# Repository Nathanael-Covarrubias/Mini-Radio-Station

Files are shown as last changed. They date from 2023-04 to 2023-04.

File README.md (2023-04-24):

# Mini-Radio-Station
FM Transmitter-NS73M

This project is a simple FM Transmitter that is deisgned to be a module for the M5 Stick C Plus. Here is a link to the parts on Digikey https://www.digikey.com/en/mylists/list/XUSR3FV555. However, the NS73M is no longer active, so it's not in the Digikey Cart but if you have one feel free to try this simple design. The xlsx file is just a Excel Sheet with information on each part.

The pdf's are just print out's of the eagle schematic and board. They are simply for reference. The Eagle files are the library or .lbr (which contains all the necessary components for the PCB), the schematic or .sch (which contains the PCB symbols), and the board or .brd (which has the actual pcb layout). This project does have Boards on OSHPark already and it is called Mini Radio Station.

The stl files are the case files that are ready to be 3D printed. If any modifications want to be made the f3d file is the actual fusion 360 drawing. 

Lastly, the arduino code is the ino file. This code is incomplete as the module can only be on one frequency, but you can reprogram it to be on the appropriate frequency. With some improvement a better version would allow the buttons on the M5 Stick C Plus to change frequencies. I would suggest using https://github.com/poelstra/arduino-multi-button.

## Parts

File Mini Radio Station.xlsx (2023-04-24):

Country of Origin may be different at time of shipment.
The HTSUS and ECCN information shown is for informational purposes only and is not a representation or warranty as to the accuracy or reliability of these classifications. All information is provided "as is" and is subject to change without notice. Any use made of the information provided is without recourse to Digi-Key and at the user's risk.
Index | Manufacturer Part Number | Manufacturer Name | Description | Availability | Stock Status | Attrition % | Requested Quantity 1 | Pack Quantity 1 | Pack Type 1 | Digi-Key Part Number 1 | Unit Price 1 | Extended Price 1 | Minimum Order Quantity 1 | Customer Reference | Requested Part Number | Lead Weeks | Datasheet | Reference Designator | US Import Tariff | Note | Part Status | RoHS Status | ECCN | HTSUS | Country of Origin | Environmental Information | Original Part numbers | Image
1 | CMA-4544PF-W | CUI Devices | MIC COND ANLG OMNI -44DB 0.382"D | 31,346 | In Stock |  | 1 | 1 | Box | 102-1721-ND | 0.78000 | $0.78 | 1 |  | 102-1721-ND | 10 | https://www.cuidevices.com/product/resource/cma-4544pf-w.pdf |  | May apply on shipments to the U.S. |  | Active | ROHS3 Compliant | EAR99 | 8518.10.8030 | China | https://www.cuidevices.com/product/resource/material-compliance/cma-4544pf-w | 102-1721-ND | https://media.digikey.com/photos/CUI%20Photos/MFG_CMA-4544PF-W.jpg
2 | ERJ-P06J103V | Panasonic Electronic Components | RES SMD 10K OHM 5% 1/2W 0805 | 579,640 | In Stock |  | 1 | 1 | Cut Tape (CT) | P10KADCT-ND | 0.12000 | $0.12 | 1 |  | P10KADCT-ND | 18 | https://industrial.panasonic.com/cdbs/www-data/pdf/RDO0000/AOA0000C331.pdf |  | N/A |  | Active | ROHS3 Compliant | EAR99 | 8533.21.0030 | Japan | https://industrial.panasonic.com/cdbs/www-cgi/auto-publishing.cgi?type=ROSU&region=WW&layer=4&cd=AOA0002 | P10KADCT-ND | https://media.digikey.com/Renders/Panasonic%20Renders/ERJ-0805%20Pkg.jpg
3 | GCM2195C1K103FA16D | Murata Electronics | CAP CER 10000PF 80V C0G/NP0 0805 | 1,412 | In Stock |  | 1 | 1 | Cut Tape (CT) | 490-GCM2195C1K103FA16DCT-ND | 0.49000 | $0.49 | 1 |  | 490-GCM2195C1K103FA16DCT-ND | 23 | https://search.murata.co.jp/Ceramy/image/img/A01X/G101/ENG/GCM2195C1K103FA16-01.pdf |  | N/A |  | Active | ROHS3 Compliant | EAR99 | 8532.24.0020 | Japan |  | 490-GCM2195C1K103FA16DCT-ND | https://media.digikey.com/Photos/Murata%20Photos/MFG_0201-(0603-Metric)-0,33mm.jpg
4 | HTSW-108-08-T-S-RA | Samtec Inc. | CONN HEADER R/A 8POS 2.54MM | 874 | In Stock |  | 1 | 1 | Bulk | HTSW-108-08-T-S-RA-ND | 0.94000 | $0.94 | 1 |  | HTSW-108-08-T-S-RA-ND | 5 |  |  | N/A |  | Active | ROHS3 Compliant | EAR99 | 8536.69.4040 | Malaysia |  | HTSW-108-08-T-S-RA-ND | https://media.digikey.com/Renders/Samtec%20Renders/HTSW-108-08-T-S-RA.JPG
5 | ESR10EZPF1001 | Rohm Semiconductor | RES SMD 1K OHM 1% 0.4W 0805 | 1,040,506 | In Stock |  | 2 | 2 | Cut Tape (CT) | RHM1.00KAECT-ND | 0.21000 | $0.42 | 1 |  | RHM1.00KAECT-ND | 13 | https://fscdn.rohm.com/en/products/databook/datasheet/passive/resistor/chip_resistor/esr-e.pdf |  | N/A |  | Active | ROHS3 Compliant | EAR99 | 8533.21.0030 | Philippines |  | RHM1.00KAECT-ND | https://media.digikey.com/Renders/Rohm%20Renders/ESR01.jpg
6 | EEE-FK1A560SR | Panasonic Electronic Components | CAP ALUM 56UF 20% 10V SMD | 6,963 | In Stock |  | 1 | 1 | Cut Tape (CT) | PCE5150CT-ND | 0.61000 | $0.61 | 1 |  | PCE5150CT-ND | 33 | https://api.pim.na.industrial.panasonic.com/file_stream/main/fileversion/3101 |  | N/A |  | Not For New Designs | ROHS3 Compliant | EAR99 | 8532.22.0020 | Malaysia |  | PCE5150CT-ND | https://media.digikey.com/Photos/Panasonic%20Photos/MFG_FKS-V-Series.jpg
7 | AB26T-32.768KHZ-E | Abracon LLC | CRYSTAL 32.7680KHZ 12.5PF TH | 4,983 | In Stock |  | 1 | 1 | Bulk | 535-14325-ND | 0.15000 | $0.15 | 1 |  | 535-14325-ND | 31 | https://abracon.com/Resonators/AB26T.pdf |  | May apply on shipments to the U.S. |  | Active | ROHS3 Compliant | EAR99 | 8541.60.0010 | China | https://abracon.com/Support/RoHS/Resonators/AB26T-Series%20RoHS2%20%20CoC%20-A.pdf|https://abracon.com/uploads/resources/REACH-224-SVHC-Certificate-Rev-S-2022-06-17-ABRACON-LLC.pdf | 535-14325-ND | https://media.digikey.com/renders/Abracon%20Renders/AB26T.jpg

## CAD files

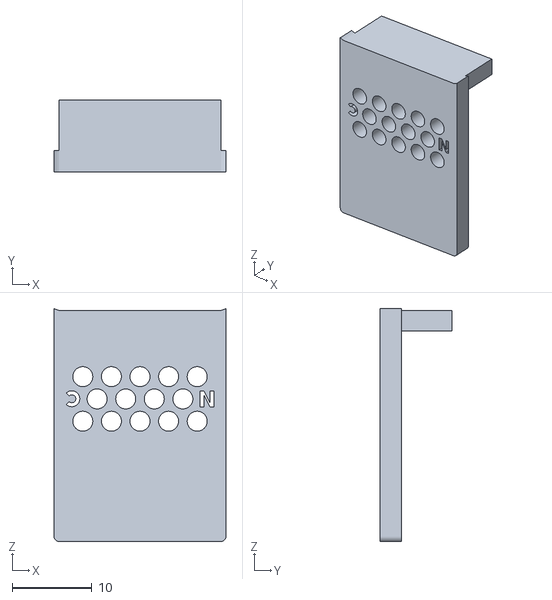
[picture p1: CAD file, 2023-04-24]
Mini Radio Station Lid.stl
21.5 x 9.00 x 29.2

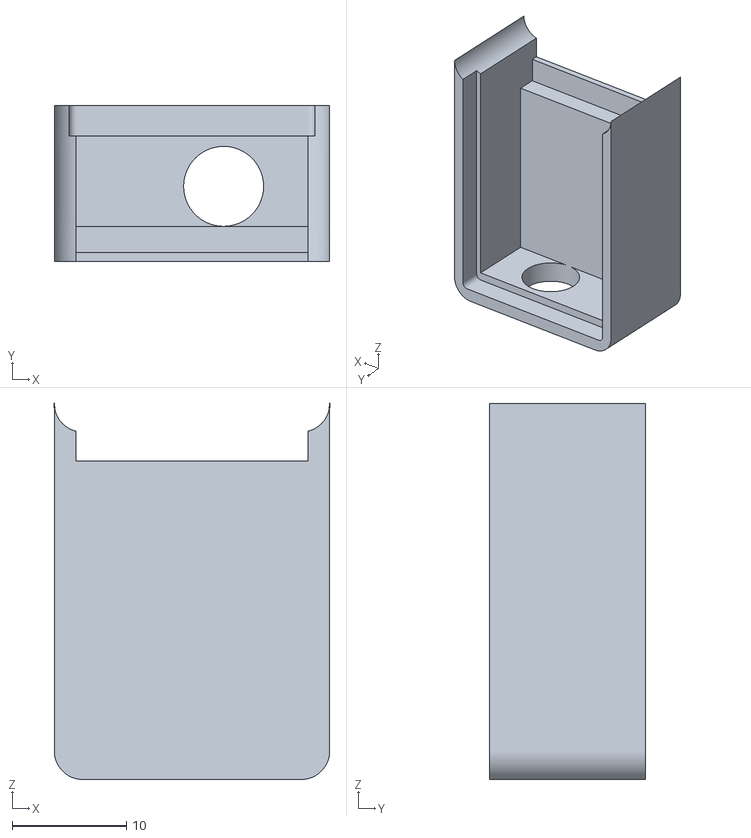
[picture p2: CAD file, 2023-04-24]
Mini Radio Station Case.stl
24.1 x 13.7 x 32.9

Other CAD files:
_Mini Radio Station-Simple Case.05f71377-dc7e-47c3-8c6b-2b0f3f518955.f3d

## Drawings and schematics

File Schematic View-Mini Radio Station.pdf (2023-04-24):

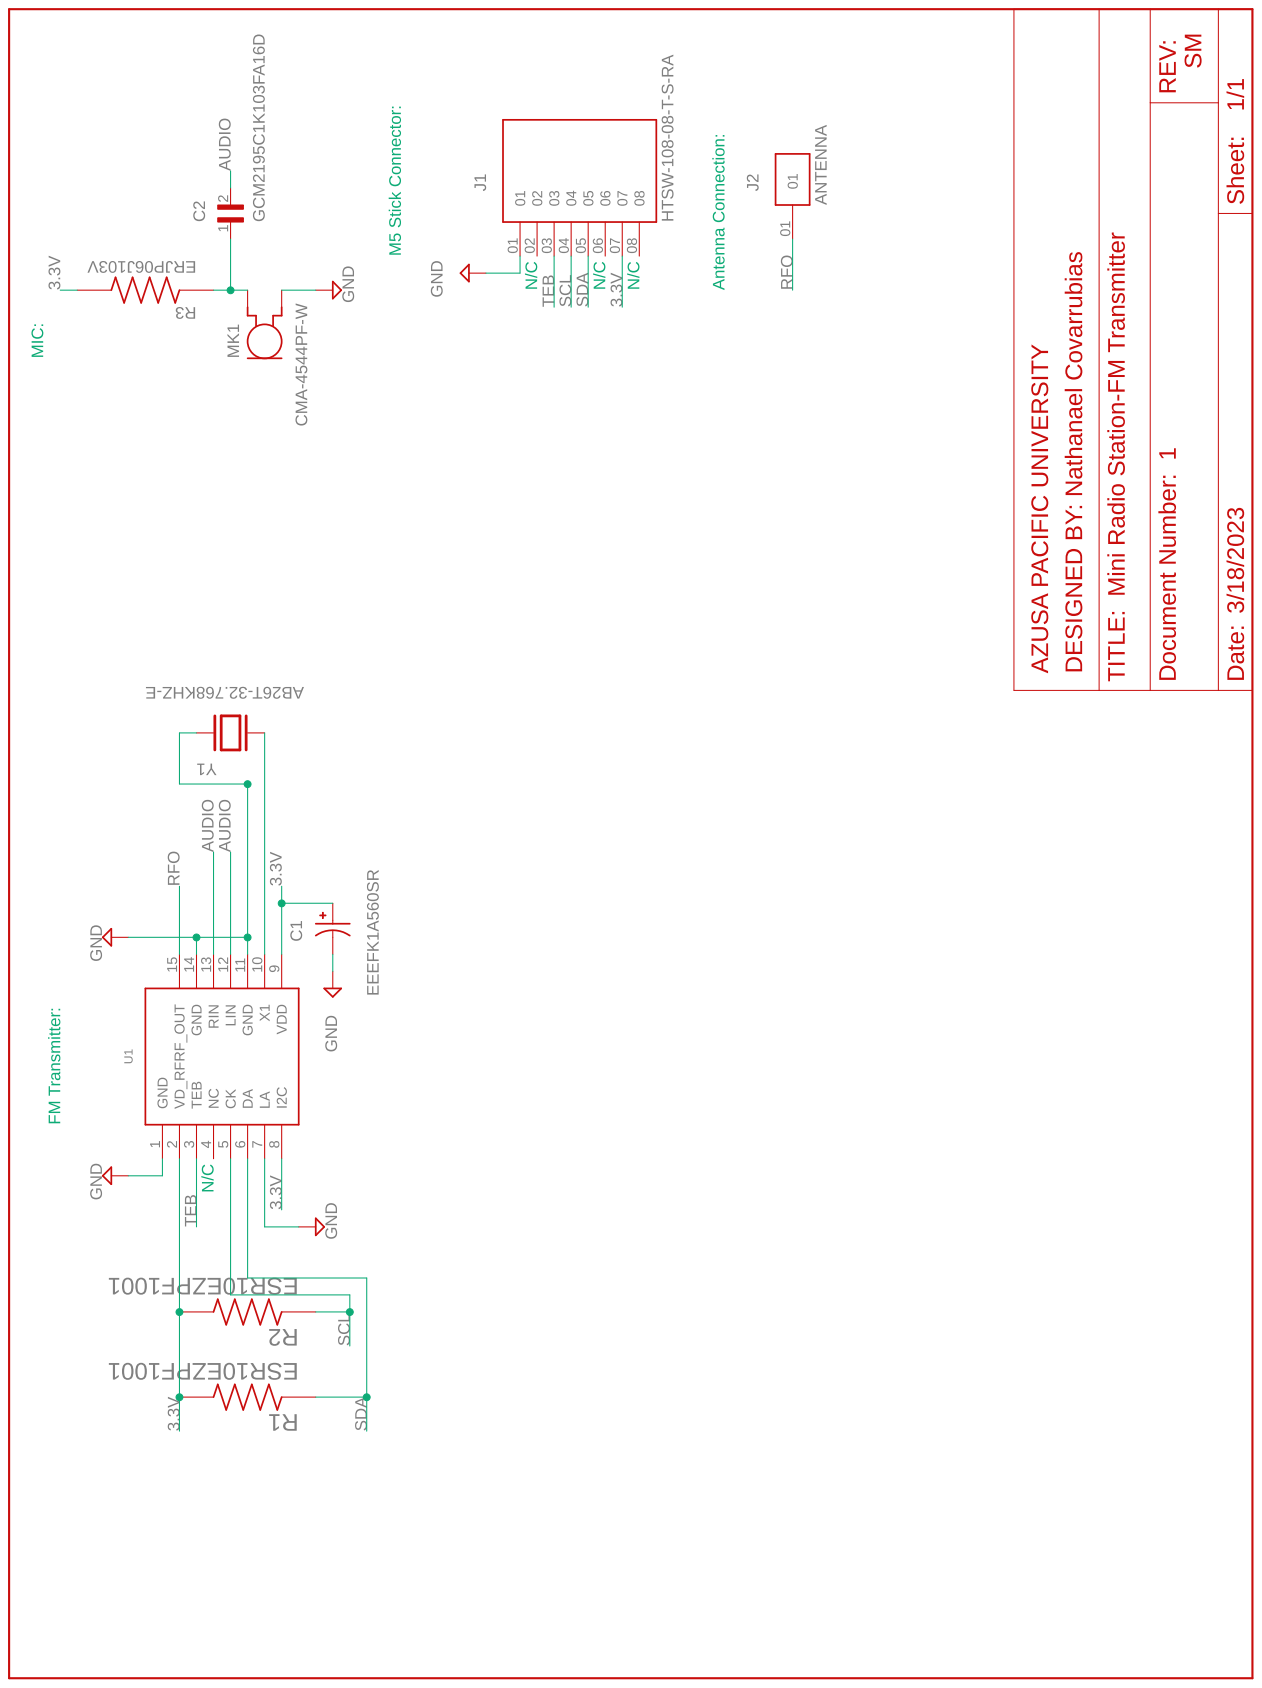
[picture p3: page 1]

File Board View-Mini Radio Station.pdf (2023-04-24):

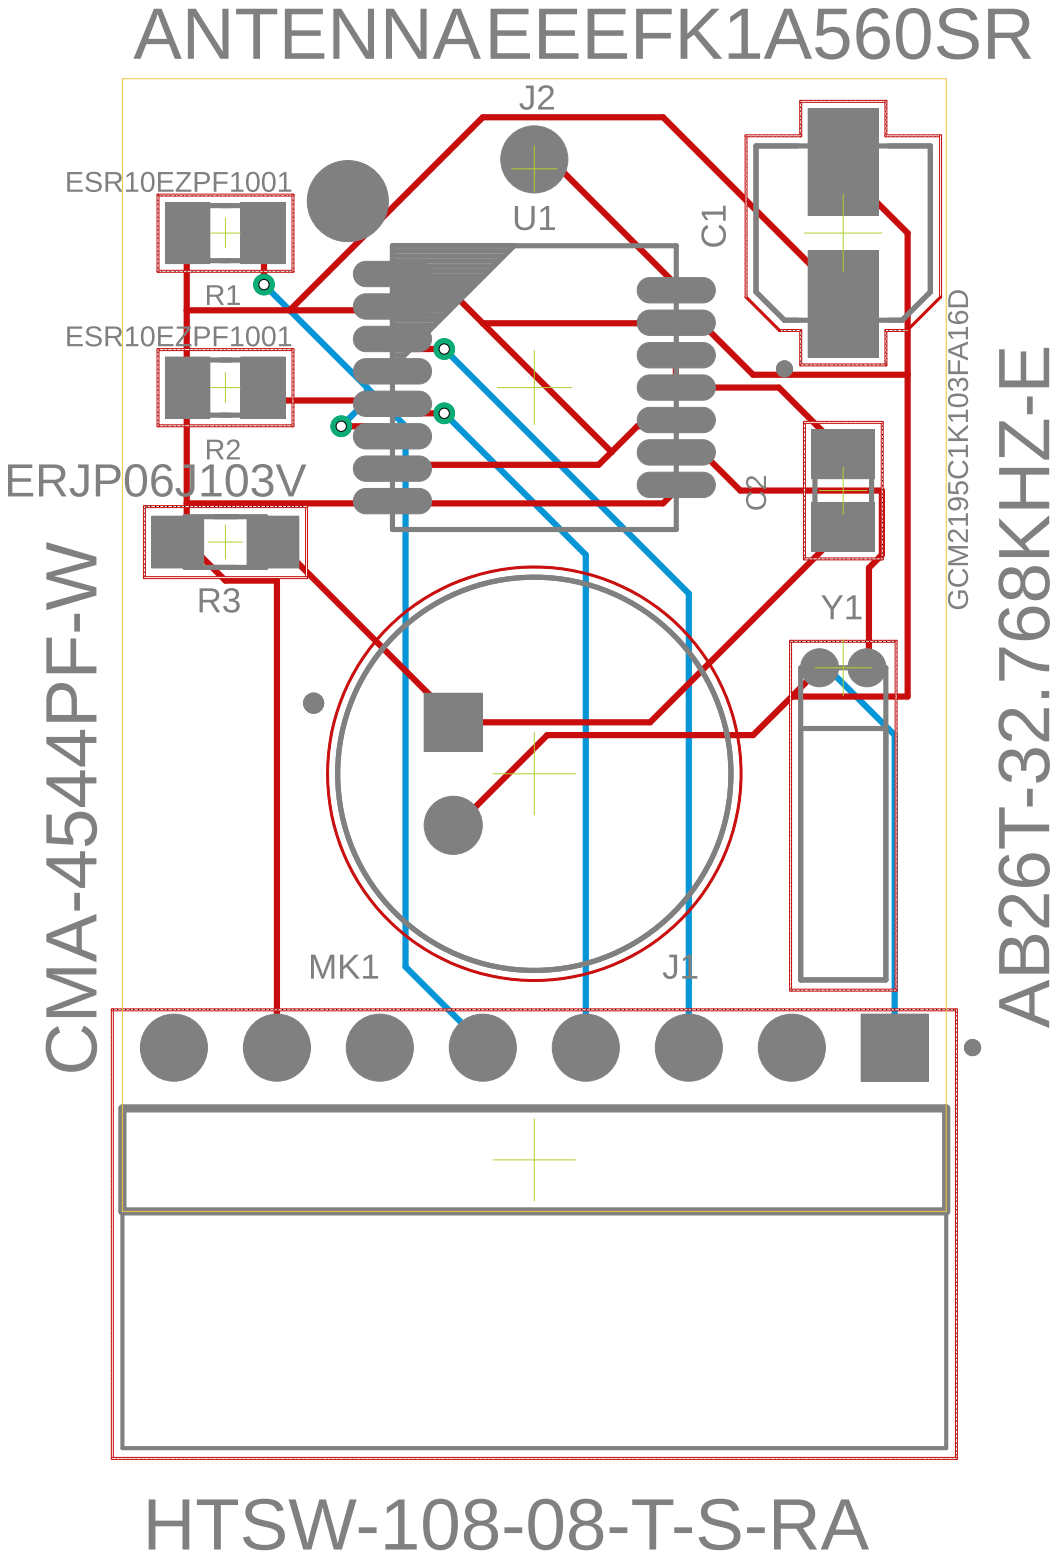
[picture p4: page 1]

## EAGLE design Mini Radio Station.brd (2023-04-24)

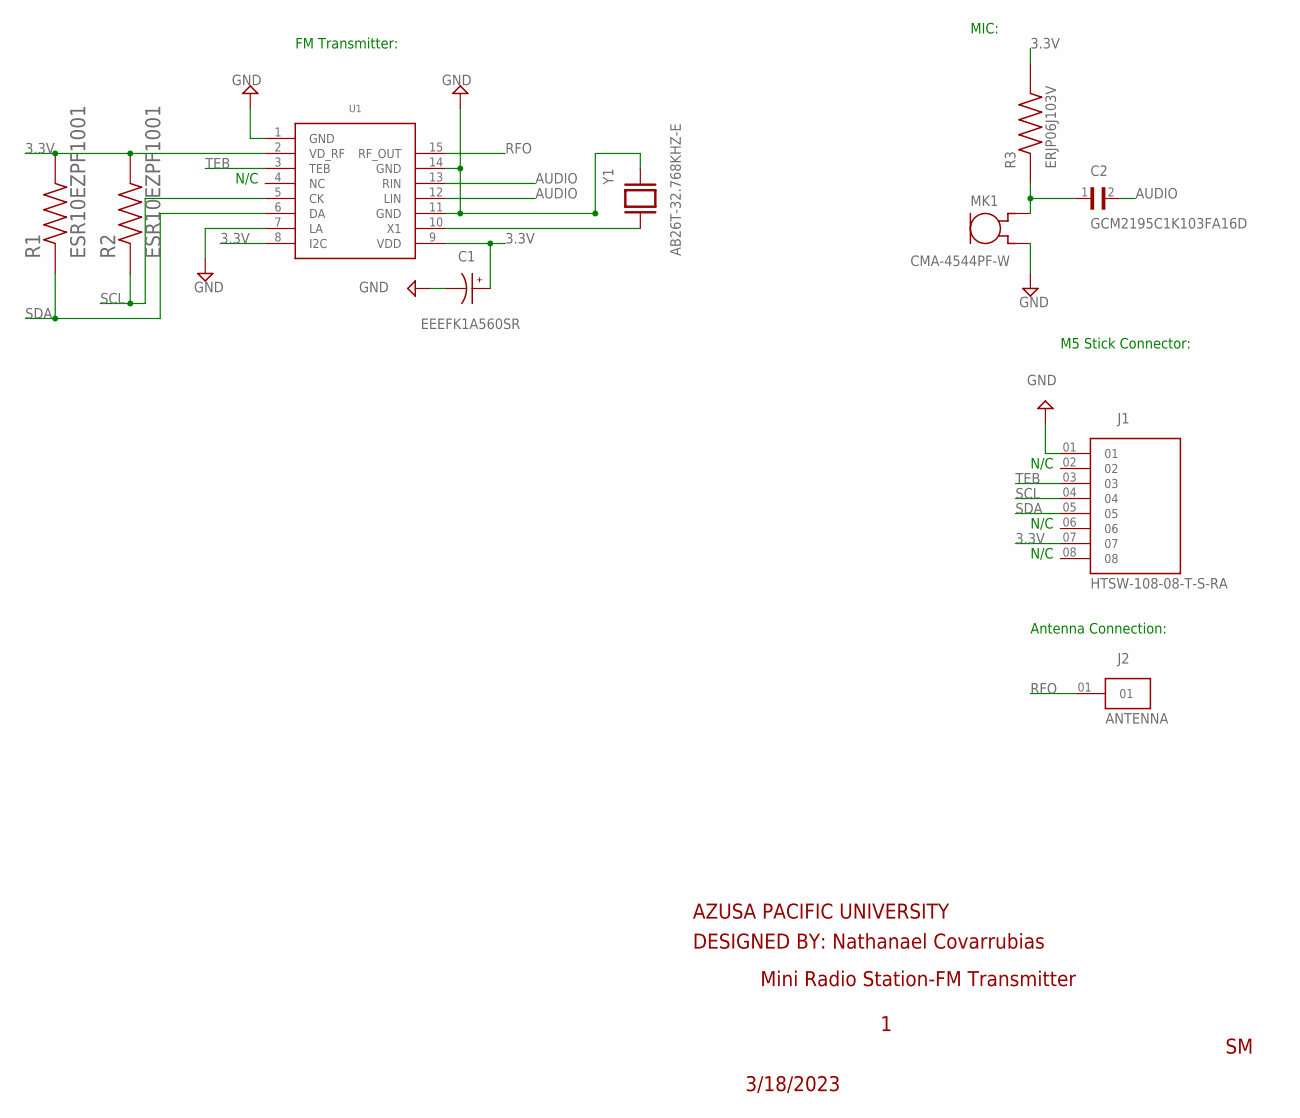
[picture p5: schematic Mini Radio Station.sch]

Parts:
C1: EEEFK1A560SR; CAP_EEEFK1A560SR
C2: GCM2195C1K103FA16D; CAPC2012X95N
J1: HTSW-108-08-T-S-RA; SAMTEC_HTSW-108-08-T-S-RA
J2: ANTENNA
MK1: CMA-4544PF-W; MIC_CMA-4544PF-W
R1, R2: ESR10EZPF1001; RESC2012X65N
R3: ERJP06J103V; RES_ERJP06J103V
U1: NS73M
Y1: AB26T-32.768KHZ-E; XTAL_AB26T-32.768KHZ-E

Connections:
3.3V: C1.1, J1.07, R1.2, R2.2, R3.2, U1.2 (VD_RF), U1.8 (I2C), U1.9 (VDD)
AUDIO: C2.2, U1.12 (LIN), U1.13 (RIN)
GND: C1.2, J1.01, MK1.2 (GND), U1.1 (GND), U1.7 (LA), U1.11 (GND), U1.14 (GND), Y1.1
unnamed: U1.10 (X1), Y1.2
unnamed: C2.1, MK1.1 (OUT), R3.1
RFO: J2.01, U1.15 (RF_OUT)
SCL: J1.04, R2.1, U1.5 (CK)
SDA: J1.05, R1.1, U1.6 (DA)
TEB: J1.03, U1.3 (TEB)

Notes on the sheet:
Mini Radio Station-FM Transmitter
3/18/2023
AZUSA PACIFIC UNIVERSITY
DESIGNED BY: Nathanael Covarrubias
N/C
FM Transmitter:
MIC:
M5 Stick Connector:
Antenna Connection:

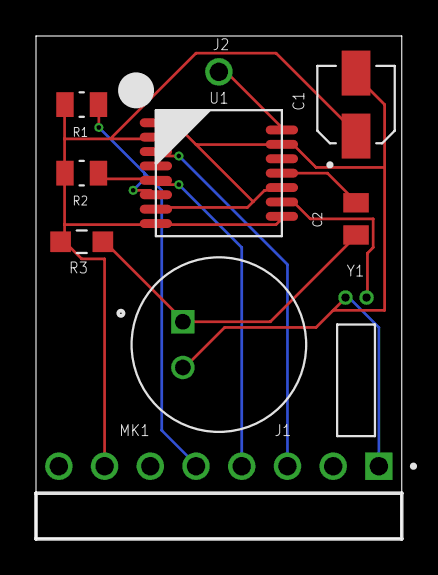
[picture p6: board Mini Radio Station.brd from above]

Board: 2 copper layers, 20.3 x 27.9 mm, 10 parts (0 on the bottom side), 9 nets.

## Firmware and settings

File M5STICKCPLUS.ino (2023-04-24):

// from https://duino4projects.com/an-fm-stereo-broadcaster-pll-using-arduino/
//  By: Cairn; caimaver (at) yahoo dot com
//  Date: 22 Mar. 2008
//  MODs by: Mike Yancey, May 12 - 14, 2008
//  Description: Uses an Arduino or compatible to control an 
//               NS73M FM Transmitter module (available from 
//               Sparkfun) on the I2C bus.

// Modified by Professor Marshall, 3/2022 for ESP32 and M5StickC-Plus.
// Modified by Nathanael Covarrubias, 4/2023 for I2C
// Unpolished, but gets the NS73M on the air as a proof-of-concept.

#include <Wire.h>
#include <M5StickCPlus.h>

#define upButton 39
// up button on pin 6
#define downButton 37                // down button on pin 5
#define setButton 26                 // set button to toggle on/off air

#define topFM  107900000            // Top of the FM Dial Range in USA
#define botFM   87500000            // Bottom of the FM Dial Range in USA
#define incrFM    200000            // FM Channel Increment in USA

long frequency = 87500000;          // the default initial frequency in Hz
long newFrequency = 0;
boolean gOnAir = false;             // Initially, NOT On The Air...

void setup() {
  M5.begin();
  M5.Lcd.fillScreen(BLACK);
  M5.Lcd.setCursor(10, 10);
  M5.Lcd.setTextColor(WHITE);
  M5.Lcd.setTextSize(1);
  M5.Lcd.printf("NS73M FM Transmitter");
  
  
  // Setup the Up/Down and SET buttons
  pinMode(upButton, INPUT);
  pinMode(downButton, INPUT);
  pinMode(setButton, INPUT);
 
  Serial.begin(115200);                 //for debugging
 
  // Attempt to read the last saved frequency from EEPROM
  ///newFrequency = loadFrequency();

  // Test if outside our FM Range...
  ///if ( newFrequency < botFM || newFrequency > topFM ) {
    // Sorry - haven't saved before - use the default.
    ///frequency = 97300000;
//  }
//  else {
    // We have a valid frequency!
    ///frequency = newFrequency;
 // }  

  M5.Lcd.setCursor(10, 35);
  M5.Lcd.printf("FM Stereo Broadcaster");
    
  displayFrequency( frequency);


  Wire.begin(0, 25);//0 is sda and 26 is scl
  // M5StickC-Plus
  // White  33 Clock SCL
  // Yellow 32 Data  SDA


  transmitter_setup( frequency );
}



void loop() {
//
//  if (digitalRead(upButton) == LOW) {
//    frequency += incrFM;                              // 200kHz steps for North American channel spacing
//    frequency = constrain( frequency, botFM, topFM);  // Keeps us in range...
//
//    Serial.println( frequency, DEC );
//    transmitter_standby( frequency );
//  }
//
//  if (digitalRead(downButton) == LOW) {
//    frequency -= incrFM;                              // 200kHz steps for North American channel spacing
//    frequency = constrain( frequency, botFM, topFM);  // Keeps us in range...
//    
//    Serial.println( frequency, DEC );
//    transmitter_standby( frequency );
//  }
  
  if (digitalRead(setButton) == LOW) {
    // Create a 'toggle' - pressing set while OnAir - set's StandBy and
    // if we're already StandBy, set the Frequency and go OnAir... 
    if ( gOnAir ) {
      transmitter_standby( frequency );
    }
    else {
      set_freq( frequency );
      //saveFrequency( frequency );     // Save the Frequency to EEPROM Memory
      delay(1000);
    }
  }
  // Lather, Rinse, Repeat....
}



void transmitter_setup( long initFrequency )
{
  i2c_send(0x0E, B00000101); //Software reset

  i2c_send(0x01, B10110100); //Register 1: forced subcarrier, pilot tone on
  
  i2c_send(0x02, B00000011); //Register 2: Unlock detect off, 2mW Tx Power

  set_freq( initFrequency);

  i2c_send(0x00, B10100001); //Register 0: 200mV audio input, 75us pre-emphasis on, crystal off, power on
  
  i2c_send(0x0E, B00000101); //Software reset
  
  i2c_send(0x06, B00011110); //Register 6: charge pumps at 320uA and 80 uA
}

void transmitter_standby( long aFrequency )
{
  i2c_send(0x00, B10100000); //Register 0: 200mV audio input, 75us pre-emphasis on, crystal off, power OFF
  
  displayFrequency( aFrequency );
  
  delay(100);
  gOnAir = false;
}

void set_freq( long aFrequency )
{
  int new_frequency;

  // New Range Checking... Implement the (experimentally determined) VFO bands:
  if (aFrequency < 88500000) {                       // Band 3
    i2c_send(0x08, B00011011);
    //Serial.println("Band 3");
  }  
  else if (aFrequency < 97900000) {                 // Band 2
    i2c_send(0x08, B00011010);
    //Serial.println("Band 2");
  }
  else if (aFrequency < 103000000) {                  // Band 1 
    i2c_send(0x08, B00011001);
    //Serial.println("Band 1");
  }
  else {
    // Must be OVER 103.000.000,                    // Band 0
    i2c_send(0x08, B00011000);
    //Serial.println("Band 0");
  }


  new_frequency = (aFrequency + 304000) / 8192;
  byte reg3 = new_frequency & 255;                  //extract low byte of frequency register
  byte reg4 = new_frequency >> 8;                   //extract high byte of frequency register
  i2c_send(0x03, reg3);                             //send low byte
  i2c_send(0x04, reg4);                             //send high byte
  
  i2c_send(0x0E, B00000101);                        //software reset  

  Serial.print("Frequency changed to ");
  Serial.println(aFrequency, DEC);

  i2c_send(0x00, B10100001); //Register 0: 200mV audio input, 75us pre-emphasis on, crystal off, power ON

  M5.Lcd.setCursor(10, 70);
  M5.Lcd.printf("On Air");
  Serial.println("On Air");
  
//  lcd.cursorTo(2, 0); 
//  lcd.printIn( " On Air ");
  gOnAir = true;
}

void i2c_send(byte reg, byte data)
{ 
    Wire.beginTransmission(0x66);               // transmit to device 1100111
    Wire.write(reg);                                 // sends register address
    Wire.write(data);                                // sends register data
    Wire.endTransmission();                         // stop transmitting
    delay(5);                                       // allow register to set
    //how do we ask if it was sent sucessfully?
}

void saveFrequency ( long aFrequency ) 
{
  ///long memFrequency = 0;                   // For use in Read / Write to EEProm

  Serial.print( "Fake Saving: " );
  Serial.println(aFrequency, DEC);

  //memFrequency = aFrequency / 10000;
  ///EEPROM.write( 0, memFrequency / 256);   // right-most byte
  ///EEPROM.write( 1, memFrequency - (memFrequency / 256) * 256 );   // next to right-most byte
}

long loadFrequency ()
{
  long memFrequency = 0;                   // For use in Read / Write to EEProm

  ///memFrequency = EEPROM.read(0) * 256 + EEPROM.read(1);
  ///memFrequency *= 10000;

  //Serial.print("Retrieving: " );
  //Serial.println(memFrequency, DEC);
  return  memFrequency;
}


void displayFrequency( long aFrequency)
{

}
